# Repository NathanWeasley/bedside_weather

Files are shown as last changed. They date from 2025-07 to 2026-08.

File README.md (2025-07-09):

# Bedside Table Weather Station
An ESP8266/STM32G0-based LED matrix display designed to be a small-sized clock & weather station that can be placed on a bedside table.

## Why build this?
1. My wife has this habit that the first thing she does after wokeup is to fetch for her phone, ask siri about today's weather so she gets to know what to wear. A dedicated weather indicator makes this procedure simpler.
2. I just got a couple of this static monochrome 16x25 LED display module, with an STM32G070KBU6 that without its serial-wire debug interface disabled. The module is possibly scrapped from some electric bicycle since its default input voltage is up to 20V. Given reason 1, this module may just be the right component.
3. I just bought a Bambu Lab H2D, the performance and multifunctionality of this thing may just allow me to build a deligate enclosure for the weather station.

## Features (planned)
1. Weather + time acquisation from internet.
2. Vibration detect (slapping).
3. Brightness adaption.
4. Special effect pattern when not activated.

## First step: Reverse-Engineering the module
Since this is a pre-made module, first step is to reverse-engineer.

Objectives:
1. Finding power scheme - done
2. Finding MCU debug interface - done
3. Finding connections between MCU and LED drivers - done
4. Finding algorithms used to drive the LEDs - done

This is a static LED matrix - meaning in theory there is no need to do any form of scan, which then implies this module can reach ridiculously high refresh rates - 400 monochrome LEDs can be updated at 40kHz if a 16MHz shift clock is used.

The original firmware onboard automatically runs a test pattern of lighting all the LEDs at three different brightnesses. The algorithm used can be identified by probing the pins with an oscilloscope, and it turns out The original firmware does the grayscale control through brute-force Binary Code Modulation (BCM):

1. LAT signal is at 40kHz.
2. CLK signal is at 16MHz, and non-stopping.
3. DAT signal is at ~156Hz, all-low for full brightness. This is also the fps.
4. OE signal is always enabled.

Based on these observations, it's quite straight forward to calculate the update-per-frame as $40000 / 156 \approx 256$. This indicates the maximum grayscales this algorithm can reach is 8-bits. The only difference that in real BCM non-stopping update is not required, you do not need to update LEDs every tick, you only need to update 8 times at the correct timing.

This is actually more reasonable than original BCM because managing data transfer at the correct timing brings additional complexity to the system. Transferring same data many many times costs nothing but power consumption, which is of least concern in an LED-orinted product. And by the non-stoppping clock signal we can conclude the original firmware utilizes I2S+DMA (SPI+DMA will result in small delays between each transfer). DMA is set to circular mode.

The only issue with this design is its LAT output: Physically this signal comes from pin 16 of STM32G070KBU6, which is neither the NSS output of SPI, nor the WS output of I2S. Peripherals can be connected to this pin includes GPIO, Timers, USARTs and EVENTOUT. The possible scheme is to start a separate timer that is synchronized to the transfer and provide LAT signal through output compare.

## Second step: Replicate LED driver

Based on the hardware connections and the internal design, Since I'm unfamiliar with I2S I've decided to still go with SPI.

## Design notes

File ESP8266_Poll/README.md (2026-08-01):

# ESP8266 天气桥接器

本工程负责连接 Wi-Fi、通过 NTP 校时、获取心知天气的 3 天逐日预报，并通过 115200-8-N-1 串口向 STM32 发送二进制帧。逐小时预报代码仍然保留，但默认关闭。

## 配置与编译

1. 将 `secrets.example.h` 复制为 `secrets.h`，填写 Wi-Fi 和心知天气 API Key。`secrets.h` 已被 Git 忽略。
2. 在 `settings.h` 中设置地点、时区和刷新周期。默认地点为西安，时区为中国标准时间。
3. 使用 Arduino IDE 打开 `ESP8266_Poll.ino`，选择实际 ESP8266 板型后编译烧录。依赖 ESP8266 Arduino Core 和 ArduinoJson。

`settings.h` 中的 `ENABLE_HOURLY_FORECAST` 默认为 `0`，此时不会请求逐小时接口，也不会执行 08:00–18:00 天气变化提取。以后获得“24 小时逐小时天气预报”权限后可将其设为 `1`；逐小时接口只能返回当前时刻之后的数据，若设备在 08:00 以后才联网，天气响应的 `WEATHER_PARTIAL_DAY` 位会置 1。

## 串口协议

帧格式为：

`AA 55 | 地址(1) | 载荷长度小端(2) | 载荷(N) | 累加校验(1)`

校验值为地址、长度高字节、长度低字节以及全部载荷字节的 8 位累加和。所有多字节整数均按小端发送，所有载荷结构按 1 字节对齐。

MCU 请求载荷仅有一个字节：`1` 查询网络状态，`2` 查询时间，`3` 查询天气。响应地址如下：

| 地址 | 响应 | 载荷长度 |
| --- | --- | ---: |
| 10 | 网络状态 | 1 |
| 11 | 本地日期时间 | 9 |
| 12 | 天气汇总 | 81 |

天气汇总包含 3 天的最高/最低温、日间/夜间天气代码，以及当天 08:00–18:00 中“首个可用时点 + 天气代码变化时点”。结构的权威定义见 `protocol.hpp`；STM32 侧镜像定义位于 `App/v1/weather_protocol.h`。

## 运行策略

- 上电联网后立即拉取并主动发送一次天气与时间。
- 每次发送天气时，00:00（含）至 21:00（不含）把当天预报放入 `daily[0]`，21:00 起把次日预报放入 `daily[0]`；发出的 `daily_count` 为 1。
- 天气默认每 30 分钟刷新；失败后每 5 分钟重试，并在仍有旧数据时携带 `WEATHER_STALE` 标志返回缓存。
- 时间由 NTP 同步，每小时主动发送一次，也可由 MCU 随时查询。
- MCU 协议使用 `Serial`；可选调试日志使用 TX-only 的 `Serial1/GPIO2`，默认关闭，避免破坏二进制帧。

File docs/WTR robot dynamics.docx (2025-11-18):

Dynamics modelling of WTR robots

I Modelling the robot

For WTR robots, consider 3 connected links on the plane, with for following parameters:

| Link 1 | Link 2 | Link 3 | Link 4
Mass | m_1 | m_2 | m_3 | m_4
Length | L_1 =0 | L_2 | L_3 | L_4
Joint | d_1 | θ_2 | θ_3 | θ_4
Center of mass distance (w.r.t. head) | L_(c1) =0 | L_(c2) | L_(c3) | L_(c4)
Center of mass (w.r.t. head) | c_1 | c_2 | c_3 | c_4
Center of mass (w.r.t. world/base) | P_(c1) | P_(c2) | P_(c3) | P_(c4)
Inertia (w.r.t. CoM) | N/A | I_(zz2) | I_(zz3) | I_(zz4)

Green parameters are provided during design and considered as constants, blue parameters are derived parameters and are dependent of variables. Red parameters are the variables.
Associated frames and configuration are shown below:

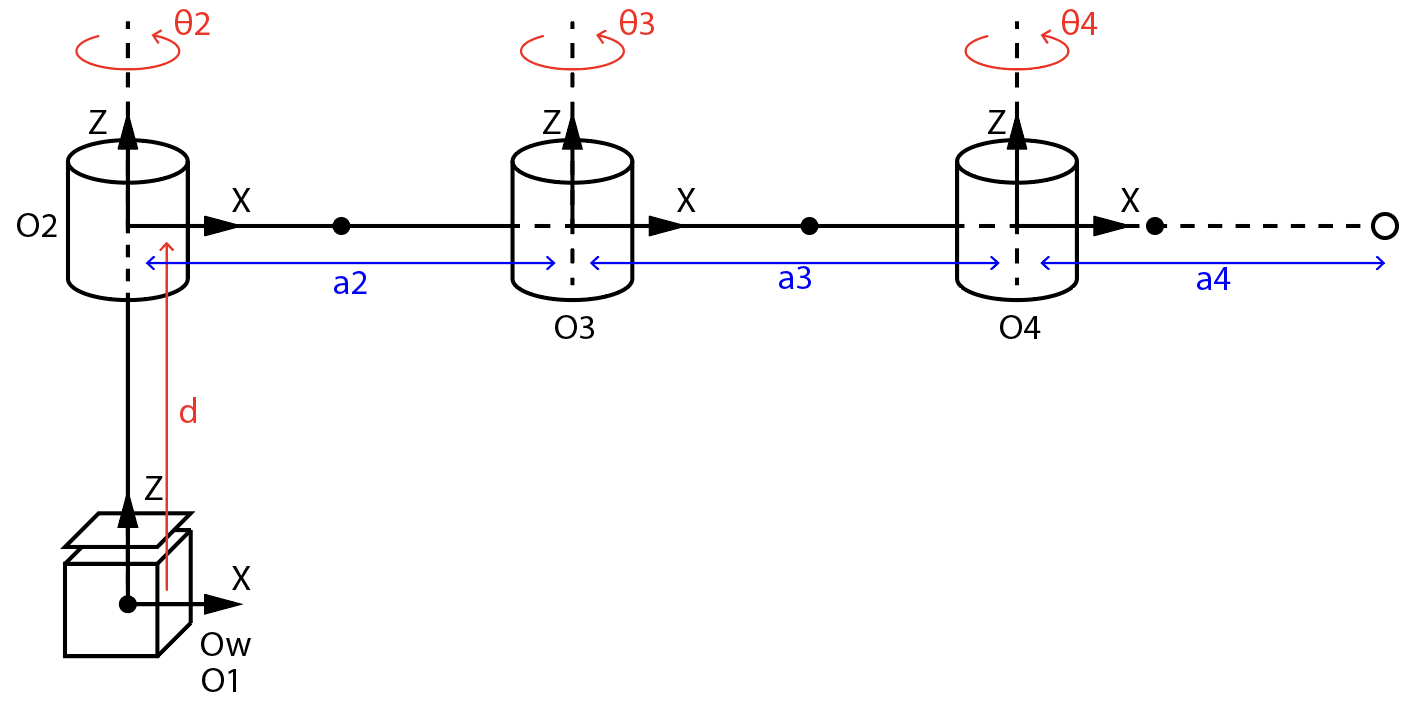
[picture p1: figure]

The corresponding modified DH parameters are:

i-th Joint | θ_i | a_(i-1) | d_i | α_(i-1) | Type
1 | 0 | 0 | q_1 =d_1 | 0 | Prismatic
2 | q_2 =θ_2 | L_1 | 0 | 0 | Revolute
3 | q_3 =θ_3 | L_2 | 0 | 0 | Revolute
4 | q_4 =θ_4 | L_3 | 0 | 0 | Revolute
5 | N/A | L_4 | N/A | 0 | N/A

II Deriving kinematic matrices

1. Using DH matrices

According to the modified DH convention, the transformation of a state in homogeneous coordinate is done by modelling the parameters θ,d,a,α sequentially:

T_i^(i-1) =Rot_X (α_(i-1) )Trans_X (a_(i-1) )Rot_Z (θ_i )Trans_Z (d_i ) =[cosθ_i , -sinθ_i , 0, a_(i-1) sinθ_i cosα_(i-1) , cosα_(i-1) cosθ_i , -sinα_(i-1) , -sinα_(i-1) d_i sinθ_i sinα_(i-1) , sinα_(i-1) cosθ_i , cosα_(i-1) , cosα_(i-1) d_i 0, 0, 0, 1]

Note the 0-th DH parameter is considered to be zero.

Since for WTR/SCARA-type robots, we always have α_i =0 , T_i^(i-1) can be simplified:

T_i^(i-1) =[cosθ_i , -sinθ_i , 0, a_(i-1) sinθ_i , cosθ_i , 0, 00, 0, 1, d_i 0, 0, 0, 1]

For all 4 joints, we have the total transformation matrix:

T_4^0 =T_1^0 T_2^1 T_3^2 T_4^3

Or generally for the i-th link, the transformation matrix can be defined as:

T_i^0 =∏_(j=1)^i T_j^(j-1)

And for mass center c_i defined in the local frame of each link, they can be transformed into world frame:

c_i^0 =T_i^0 c_i =P_(ci)

Deriving the mass center of each link is crucial for constructing the Lagrangian – we need the kinetic energy and potential energy for each link, which are usually defined around the link’s mass center.

2. Using direct geometrical calculation

Another way of deriving the mass center location is through the geometry of the robot, which involves no transformation matrices. This method can be intuitive for robots with only a few joints.

First, we derive position of the end point of each link:

p_0 =(0, 0,0)^T p_1 =p_0 +(0,0,d_1 )^T =(0,0,d_1 )^T p_2 =p_1 +(L_2 cosθ_2 ,L_2 sinθ_2 ,0)^T =(L_2 cosθ_2 ,L_2 sinθ_2 ,d_1 )^T p_3 =p_2 +(L_3 cos(θ_2 +θ_3 ),L_3 sin(θ_2 +θ_3 ),0)^T =(L_2 cosθ_2 +L_3 cos(θ_2 +θ_3 ),L_2 sinθ_2 +L_3 sin(θ_2 +θ_3 ),d_1 )^T p_4 =p_3 +(L_4 cos(θ_2 +θ_3 +θ_4 ),L_4 sin(θ_2 +θ_3 +θ_4 ),0)^T =(, L_2 cosθ_2 +L_3 cos(θ_2 +θ_3 )+L_4 cos(θ_2 +θ_3 +θ_4 ), L_2 sinθ_2 +L_3 sin(θ_2 +θ_3 )+L_4 sin(θ_2 +θ_3 +θ_4 ), d_1 )

We can derive the center of mass w.r.t. the rotation axis (origin) of each link.

c_1 =(0,0,d_1 )^T c_2 =(L_(c2) cosθ_2 ,L_(c2) sinθ_2 ,0)^T c_3 =(L_(c3) cos(θ_2 +θ_3 ),L_(c3) sin(θ_2 +θ_3 ),0)^T c_4 =(L_(c4) cos(θ_2 +θ_3 +θ_4 ), L_(c4) sin(θ_2 +θ_3 +θ_4 ),0)^T

Combined we have the position of each mass center in the world frame:

P_(c1) =c_1 +p_0 =(0,0,d_1 )^T P_(c2) =c_2 +p_1 =(L_(c2) cosθ_2 ,L_(c2) sinθ_2 ,d_1 )^T P_(c3) =c_3 +p_2 =(L_(c3) cos(θ_2 +θ_3 )+L_2 cosθ_2 ,L_(c3) sin(θ_2 +θ_3 )+L_2 sinθ_2 ,d_1 )^T P_(c4) =c_4 +p_3 =(, L_(c4) cos(θ_2 +θ_3 +θ_4 )+L_2 cosθ_2 +L_3 cos(θ_2 +θ_3 ), L_(c4) sin(θ_2 +θ_3 +θ_4 )+L_2 sinθ_2 +L_3 sin(θ_2 +θ_3 ), d_1 )

With the help of the CAS system in MATLAB we can verify the two methods yield the same result.

III Forming the Lagrangian

The Lagrangian is defined by L=K-U , in which K is the total kinetic energy of the system and U is the total potential energy of the system. Physically the above energies can be defined using the object’s mass center:

K_i =1/2m_i v_(ci)^T v_(ci) +1/2ω_i^T I_i ω_i

For WTR/SCARA-type robots, all joints rotate around their Z axis, therefore the second term can be simplified to only involving the joint velocity and the inertia around the Z axis at the mass center:

K_i =1/2m_i v_(ci)^T v_(ci) +1/2I_(zzi) θ_i^2

1. Kinetic energy using joint velocity

Since in the end we want the relationship between joint torque and joint position, velocity, acceleration, etc., it’s better to formulate kinetic energy in terms of the joint variables q, q,q . This can be done by taking the derivative of mass centers w.r.t. joint variables, more specifically, joint velocities:

K_i =1/2q^T D_i (q)q D_i =(∂P_(ci))/(∂q)

D_i (q) is called the inertia matrix of this link. The total kinetic energy K is formed by summing individual kinetic energy of each link:

K=∑_(i=1)^n K_i =1/2q^T M(q)q

M(q) is called the mass matrix of the robot. As later we’ll see, this is one of the terms we want for calculating the inverse dynamics.

Deriving the mass matrix by taking derivatives can be a mess if you do it by hand. Instead, it can be done by utilizing link Jacobian:

J_i =[J_(vi)^T , J_(ωi)^T ]^T

The link Jacobian transforms the joint velocity to velocity of the link’s mass center in world frame.

Link Jacobian can be derived as:

J_i =[r_(vi_1) , r_(vi_2) , ⋯, r_(vi_n) r_(ωi_1) , r_(ωi_2) , ⋯, r_(ωi_n) ]_(6×n)

For revolute joints:

r_(vi_j) ={, z_j ×(P_(ci) -p_j ), j≤i, 0, j>i r_(ωi_j) ={, z_j , j≤i, 0, j>i

For prismatic joints:

r_(vi_j) ={, z_j , j≤i, 0, j>i r_(ωi_j) =0

z_j is the representation of Z axis of the j-th link in world frame, it’s also the third column of the rotation matrix part in the total homogeneous matrix up till this link: p_j represents the origin of the j-th link, it’s also the translational part of the total homogeneous matrix up till this link.

T_j^0 =[R_j^0 , p_j 0, 1]=[[x_j , y_j , z_j ], p_j 0, 1]

In total the link Jacobian provides the overall contribution of each joint to the i-th mass center in world frame. Utilizing the link Jacobian, link velocity and angular velocity is just:

v_(ci) =J_(vi) q ω_i =J_(ωi) q

In order to calculate energy, we need the inertia of each link to be represented in the world frame. This can be done by utilizing the rotation part of the total homogeneous matrix up till this link:

I_i^0 =R_i^0 I_i R_i^0 ^T

Finally, we can rewrite the kinetic energy in these terms:

K_i =1/2m_i (J_(vi) q)^T (J_(vi) q)+1/2(J_(ωi) q)^T I_i^0 (J_(ωi) q) =1/2q^T m_i J_(vi)^T J_(vi) q+1/2q^T J_(ωi)^T I_i^0 J_(ω_i) q =1/2q^T D_i (q)q

Among which:

D_i (q)=m_i J_(vi)^T J_(vi) +J_(ωi)^T I_i^0 J_(ω_i)

And adding the above kinetic energy for all links we have the explicit form of total kinetic energy, also the mass matrix.

For the potential energy, it’s only related to gravity (no springs are involved):

U_i =[0, 0, 1]m_i gp_i

2. Kinetic energy using Cartesian velocity

If you already derived the mass center location in analytical form, then the most intuitive way is to get velocity simply by taking its derivative w.r.t. time.

For later simplicity we calculate local direction of each link in world frame:

r_1 =(, 0, 0, 1) r_2 =(, -sinθ_2 , cosθ_2 , 0) r_3 =（, -sin（θ_2 +θ_3 ）, cos（θ_2 +θ_3 ）, 0） r_4 =(, -sin(θ̇_2 +θ_3 +θ_4 ), cos(θ̇_2 +θ_3 +θ_4 ), 0)

Mass center velocity can be seen as a combination of the above directions:

v_(c1) =d_1 r_1 v_(c2) =L_(c2) θ_2 r_2 +d_1 r_1 v_(c3) =L_(c3) (θ_2 +θ_3 )r_3 +L_2 θ_2 r_2 +d_1 r_1 v_(c4) =L_(c4) (θ_2 +θ_3 +θ_4 )r_4 +L_3 (θ_2 +θ_3 )r_3 +L_2 θ_2 r_2 +d_1 r_1

We then derive kinetic and potential energy for each link.

Kinetic energy (described per link as the combination of rotational and translational movement):

K_1 =1/2m_1 v_(c1)^2 K_2 =1/2I_(zz2) θ_2^2 +1/2m_2 v_(c2)^2 K_3 =1/2I_(zz3) (θ_2 +θ_3 )^2 +1/2m_3 v_(c3)^2 K_4 =1/2I_(zz4) (θ_2 +θ_3 +θ_4 )^2 +1/2m_4 v_(c4)^2

Potential energy:

U_1 =m_1 gd_1 U_2 =m_2 gd_1 U_3 =m_3 gd_1 U_4 =m_4 gd_1

IV Solving the Euler-Lagrange equation

Given Lagrangian L , we have total generalized (non-conservative) force defined by the Euler-Lagrange equation:

d/(dt)((∂L)/(∂q))-(∂L)/(∂q)=F

Inverse dynamics involves solving this equation for F .

Since L is a function of q, q only, (∂L)/(∂q) is also a function of q, q only. This means the time derivative term can be expanded using chain rule:

d/(dt)((∂L)/(∂q))=(∂^2 L)/(∂q∂q)q+(∂^2 L)/(∂q^2)q

Which yields:

F=(∂^2 L)/(∂q∂q)q+(∂^2 L)/(∂q^2)q-(∂L)/(∂q)

Since we have the Lagrangian in analytical form, we can calculate each of the derivatives effectively and accurately using the technique of reverse mode automatic differentiation.

Actually, the Hessian of Lagrangian w.r.t. general velocity q is equivalent to the mass matrix M(q) , and one can directly notice that the above equation is the exact motion equation:

F=M(q)q+C(q,q)q+g(q)

Where:

M(q)=(∂^2 L)/(∂q^2) C(q,q)=(∂^2 L)/(∂q∂q) g(q)=-(∂L)/(∂q)

Note that in this direct method, the Coriolis and centrifugal matrix C(q,q) and gravity term g(q) is not unique, and it can be different from the same equation derived from other methods.

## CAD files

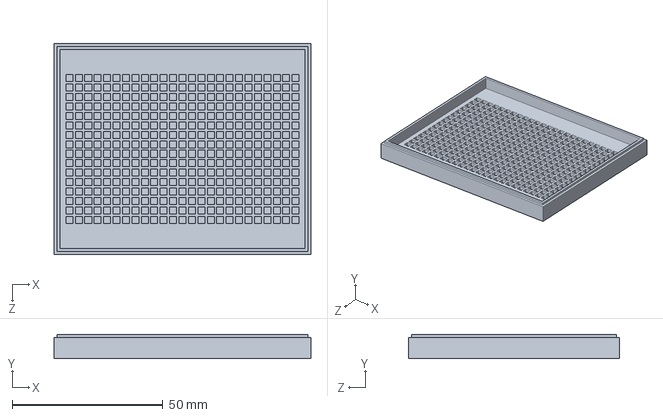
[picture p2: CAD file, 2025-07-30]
enclosure/front.SLDPRT
85.2 x 8.00 x 70.0 mm

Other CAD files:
enclosure/front_nopiller.STL
enclosure/front.STL

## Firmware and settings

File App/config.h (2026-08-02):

#pragma once

#include <stdint.h>

#ifdef __cplusplus
extern "C"
{
#endif

#define LED_HEIGHT              (16)
#define LED_WIDTH               (25)
#define LED_COLOR_DEPTH         (8)

#define LED_CNT                 (LED_HEIGHT * LED_WIDTH)
#define LED_BUFFER_SIZE         (LED_CNT/8 + ((LED_CNT%8) == 0 ? 0 : 1))
#define LED_GRAYSCALE           (1 << LED_COLOR_DEPTH)

#define DEFAULT_RX_BUFFER_SIZE  (512)
#define DEFAULT_TX_BUFFER_SIZE  (64)
#define UART_BUFFER_SIZE        (1024)

#define GFX_VPAINT_MAX_WIDTH    (500)
#define GFX_VPAINT_MAX_HEIGHT   (32)

#define TASK_MAX_TASKS          (16)
#define TASK_SCHEDULE_PERIOD_US (10000)     // 10 ms -> 100 Hz

#ifdef __cplusplus
}
#endif

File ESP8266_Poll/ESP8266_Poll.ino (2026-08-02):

#include <Arduino.h>
#include <ArduinoJson.h>
#include <ESP8266HTTPClient.h>
#include <ESP8266WiFi.h>
#include <ESP8266WiFiMulti.h>
#include <WiFiClientSecureBearSSL.h>

#include <cmath>
#include <cstdlib>
#include <ctime>

#include "protocol.hpp"
#include "secrets.h"
#include "settings.h"

using namespace bedside;

#if ENABLE_DEBUG_LOG
#define DEBUG_BEGIN(baud) Serial1.begin(baud)
#define DEBUG_PRINT(...) Serial1.print(__VA_ARGS__)
#define DEBUG_PRINTLN(...) Serial1.println(__VA_ARGS__)
#define DEBUG_PRINTF(...) Serial1.printf(__VA_ARGS__)
#else
#define DEBUG_BEGIN(baud) ((void)(baud))
#define DEBUG_PRINT(...) ((void)0)
#define DEBUG_PRINTLN(...) ((void)0)
#define DEBUG_PRINTF(...) ((void)0)
#endif

namespace
{

enum class FetchResult : uint8_t
{
    OK = 0,
    NETWORK_ERROR,
    HTTP_ERROR,
    JSON_ERROR,
};

const char* fetchResultName(FetchResult result)
{
    switch (result)
    {
    case FetchResult::OK:
        return "OK";
    case FetchResult::NETWORK_ERROR:
        return "NETWORK_ERROR";
    case FetchResult::HTTP_ERROR:
        return "HTTP_ERROR";
    case FetchResult::JSON_ERROR:
        return "JSON_ERROR";
    default:
        return "UNKNOWN";
    }
}

const char* wifiStatusName(int status)
{
    switch (status)
    {
    case WL_IDLE_STATUS:
        return "IDLE";
    case WL_NO_SSID_AVAIL:
        return "NO_SSID";
    case WL_SCAN_COMPLETED:
        return "SCAN_COMPLETED";
    case WL_CONNECTED:
        return "CONNECTED";
    case WL_CONNECT_FAILED:
        return "CONNECT_FAILED";
    case WL_CONNECTION_LOST:
        return "CONNECTION_LOST";
    case WL_DISCONNECTED:
        return "DISCONNECTED";
    default:
        return "UNKNOWN";
    }
}

String redactApiKey(const String& url)
{
    String safeUrl = url;
    const int keyStart = safeUrl.indexOf(F("key="));
    if (keyStart < 0)
    {
        return safeUrl;
    }

    const int valueStart = keyStart + 4;
    int valueEnd = safeUrl.indexOf('&', valueStart);
    if (valueEnd < 0)
    {
        valueEnd = safeUrl.length();
    }
    String redacted = safeUrl.substring(0, valueStart);
    redacted += F("<redacted>");
    redacted += safeUrl.substring(valueEnd);
    return redacted;
}

bool timeReached(uint32_t now, uint32_t deadline)
{
    return static_cast<int32_t>(now - deadline) >= 0;
}

bool parseIsoDateTime(const char* value, uint16_t& year, uint8_t& month, uint8_t& day, uint8_t& hour)
{
    if (value == nullptr || strlen(value) < 13 || value[4] != '-' || value[7] != '-' || value[10] != 'T')
    {
        return false;
    }

    year = static_cast<uint16_t>(atoi(value));
    month = static_cast<uint8_t>(atoi(value + 5));
    day = static_cast<uint8_t>(atoi(value + 8));
    hour = static_cast<uint8_t>(atoi(value + 11));
    return year >= 2000 && month >= 1 && month <= 12 && day >= 1 && day <= 31 && hour <= 23;
}

bool parseIsoDate(const char* value, uint16_t& year, uint8_t& month, uint8_t& day)
{
    uint8_t ignoredHour = 0;
    if (value == nullptr || strlen(value) < 10)
    {
        return false;
    }

    char dateTime[14] = {0};
    memcpy(dateTime, value, 10);
    memcpy(dateTime + 10, "T00", 3);
    return parseIsoDateTime(dateTime, year, month, day, ignoredHour);
}

WeatherType parseWeatherCode(JsonVariantConst value)
{
    if (value.isNull())
    {
        return WeatherType::UNKNOWN;
    }

    const int code = value.as<int>();
    if (code >= static_cast<int>(WeatherType::DAY_SUNNY) && code <= static_cast<int>(WeatherType::HOT))
    {
        return static_cast<WeatherType>(code);
    }
    return WeatherType::UNKNOWN;
}

int16_t parseTemperatureX10(JsonVariantConst value)
{
    long result = lroundf(value.as<float>() * 10.0F);
    if (result < INT16_MIN)
    {
        result = INT16_MIN;
    }
    else if (result > INT16_MAX)
    {
        result = INT16_MAX;
    }
    return static_cast<int16_t>(result);
}

void applyFetchError(uint8_t& status, FetchResult result)
{
    switch (result)
    {
    case FetchResult::NETWORK_ERROR:
        status |= WEATHER_NETWORK_ERROR;
        break;
    case FetchResult::HTTP_ERROR:
        status |= WEATHER_HTTP_ERROR;
        break;
    case FetchResult::JSON_ERROR:
        status |= WEATHER_JSON_ERROR;
        break;
    default:
        break;
    }
}

} // namespace

class WeatherBridge
{
    enum class ReadState : uint8_t
    {
        HEADER_AA = 0,
        HEADER_55,
        ADDRESS,
        LENGTH_LOW,
        LENGTH_HIGH,
        DATA,
    };

    ESP8266WiFiMulti _wifi;
    v1::Packet _rxPacket;
    v1::Packet _txPacket;
    WeatherResponse _weather{};
    ReadState _readState = ReadState::HEADER_AA;
    uint8_t* _nextRxByte = nullptr;
    uint16_t _rxBytesLeft = 0;
    uint32_t _nextWifiPoll = 0;
    uint32_t _nextWeatherRefresh = 0;
    uint32_t _nextDateTimePush = 0;
    bool _ntpStarted = false;
    bool _weatherRefreshPending = true;
    bool _lastFetchFailed = false;
    bool _wasConnected = false;
    bool _clockStatusLogged = false;
    int _lastWifiStatus = -1;

public:
    void begin()
    {
        Serial.begin(115200);
        DEBUG_BEGIN(115200);

        resetPacketReader();
        WiFi.persistent(false);
        WiFi.mode(WIFI_STA);
        WiFi.setAutoReconnect(true);
        _wifi.addAP(WIFI_SSID, WIFI_PASSWORD);

        // 用 UTC 同步系统时钟，再由 TZ 规则转换为本地时间。
        setenv("TZ", DEVICE_TIMEZONE, 1);
        tzset();
        DEBUG_PRINTLN(F("[BOOT] ESP8266 weather bridge started"));
        DEBUG_PRINTF("[BOOT] target_ssid=%s, weather_location=%s, debug_uart=Serial1/GPIO2\n",
                     WIFI_SSID, WEATHER_LOCATION);
        logWifiStatus(WiFi.status());
    }

    void tick()
    {
        processSerial();

        const uint32_t now = millis();
        if (timeReached(now, _nextWifiPoll))
        {
            _wifi.run();
            _nextWifiPoll = now + WIFI_POLL_INTERVAL_MS;

            const int wifiStatus = WiFi.status();
            if (wifiStatus != _lastWifiStatus)
            {
                logWifiStatus(wifiStatus);
            }
        }

        const bool connected = WiFi.status() == WL_CONNECTED;
        if (connected && !_wasConnected)
        {
            // 每次重新联网都立即刷新，避免继续展示断网前的缓存。
            _weatherRefreshPending = true;
        }
        _wasConnected = connected;

        if (connected)
        {
            if (!_ntpStarted)
            {
                DEBUG_PRINTF("[NTP] starting synchronization, timezone=%s\n", DEVICE_TIMEZONE);
                // 使用 POSIX 时区重载；数值型 configTime(0, 0, ...) 会把本地时区重置为 GMT。
                configTime(DEVICE_TIMEZONE, "ntp.aliyun.com", "ntp1.aliyun.com", "pool.ntp.org");
                _ntpStarted = true;
            }

            if (isClockValid() && !_clockStatusLogged)
            {
                logCurrentTime();
                _clockStatusLogged = true;
            }

            if (_weatherRefreshPending || timeReached(now, _nextWeatherRefresh))
            {
                const bool complete = refreshWeather();
                _weatherRefreshPending = false;
                _nextWeatherRefresh = now + (complete ? WEATHER_REFRESH_INTERVAL_MS : WEATHER_RETRY_INTERVAL_MS);
                sendWeather();
            }

            if (isClockValid() && timeReached(now, _nextDateTimePush))
            {
                sendDateTime();
                _nextDateTimePush = now + DATETIME_PUSH_INTERVAL_MS;
            }
        }

        yield();
    }

private:
    String makeWeatherUrl(const __FlashStringHelper* resource, const __FlashStringHelper* suffix) const
    {
        String url;
        url.reserve(192);
        url += F("https://api.seniverse.com/v3/weather/");
        url += resource;
        url += F(".json?key=");
        url += SENIVERSE_API_KEY;
        url += F("&location=");
        url += WEATHER_LOCATION;
        url += F("&language=");
        url += WEATHER_LANGUAGE;
        url += F("&unit=");
        url += WEATHER_UNIT;
        url += suffix;
        return url;
    }

    FetchResult httpGet(const String& url, String& payload)
    {
        if (WiFi.status() != WL_CONNECTED)
        {
            DEBUG_PRINTF("[HTTP] skipped: WiFi status=%s(%d)\n",
                         wifiStatusName(WiFi.status()), static_cast<int>(WiFi.status()));
            return FetchResult::NETWORK_ERROR;
        }

        const String safeUrl = redactApiKey(url);
        DEBUG_PRINTF("[HTTP] GET %s\n", safeUrl.c_str());
        const uint32_t startedAt = millis();

        BearSSL::WiFiClientSecure client;
        // ESP8266 未内置稳定的 CA 存储；HTTPS 仍可避免 API key 明文传输。
        // 如产品化部署，应改为 setTrustAnchors() 并随证书更新固件。
        client.setInsecure();

        HTTPClient http;
        http.setTimeout(HTTP_TIMEOUT_MS);
        if (!http.begin(client, url))
        {
            DEBUG_PRINTF("[HTTP] begin failed after %lu ms\n",
                         static_cast<unsigned long>(millis() - startedAt));
            return FetchResult::HTTP_ERROR;
        }

        const int code = http.GET();
        if (code > 0)
        {
            payload = http.getString();
        }
        const uint32_t elapsed = millis() - startedAt;
        DEBUG_PRINTF("[HTTP] response: code=%d, elapsed=%lu ms, bytes=%u\n",
                     code, static_cast<unsigned long>(elapsed), static_cast<unsigned>(payload.length()));

        if (code != HTTP_CODE_OK)
        {
            if (code < 0)
            {
                DEBUG_PRINTF("[HTTP] transport error: %s\n", http.errorToString(code).c_str());
            }
            else if (payload.length() > 0)
            {
                // 403 等业务错误的正文通常包含心知天气错误码，限制长度避免刷屏。
                constexpr unsigned int MAX_ERROR_BODY_LOG = 512;
                if (payload.length() > MAX_ERROR_BODY_LOG)
                {
                    payload.remove(MAX_ERROR_BODY_LOG);
                    payload += F("...<truncated>");
                }
                DEBUG_PRINTF("[HTTP] error body: %s\n", payload.c_str());
            }
            http.end();
            return code < 0 ? FetchResult::NETWORK_ERROR : FetchResult::HTTP_ERROR;
        }

        http.end();
        return payload.length() > 0 ? FetchResult::OK : FetchResult::HTTP_ERROR;
    }

    FetchResult fetchDaily(WeatherResponse& output)
    {
        String payload;
        FetchResult result = httpGet(makeWeatherUrl(F("daily"), F("&start=0&days=3")), payload);
        if (result != FetchResult::OK)
        {
            return result;
        }

#if ARDUINOJSON_VERSION_MAJOR >= 7
        JsonDocument document;
#else
        DynamicJsonDocument document(6144);
#endif
        const DeserializationError error = deserializeJson(document, payload);
        if (error)
        {
            DEBUG_PRINTF("Daily JSON error: %s\n", error.c_str());
            return FetchResult::JSON_ERROR;
        }

        JsonArrayConst daily = document["results"][0]["daily"].as<JsonArrayConst>();
        if (daily.isNull())
        {
            return FetchResult::JSON_ERROR;
        }

        output.daily_count = 0;
        for (JsonObjectConst item : daily)
        {
            if (output.daily_count >= DAILY_FORECAST_COUNT)
            {
                break;
            }

            DailyForecast& day = output.daily[output.daily_count];
            if (!parseIsoDate(item["date"].as<const char*>(), day.year, day.month, day.day) ||
                item["high"].isNull() || item["low"].isNull())
            {
                continue;
            }

            day.temp_max_x10 = parseTemperatureX10(item["high"]);
            day.temp_min_x10 = parseTemperatureX10(item["low"]);
            day.weather_day = parseWeatherCode(item["code_day"]);
            day.weather_night = parseWeatherCode(item["code_night"]);
            ++output.daily_count;
        }

        if (output.daily_count == 0)
        {
            return FetchResult::JSON_ERROR;
        }
        output.status |= WEATHER_DAILY_VALID;
        DEBUG_PRINTF("[WEATHER] daily parsed: days=%u\n", output.daily_count);
        for (uint8_t i = 0; i < output.daily_count; ++i)
        {
            const DailyForecast& day = output.daily[i];
            DEBUG_PRINTF("[WEATHER] daily[%u]: %04u-%02u-%02u, high=%s%d.%dC, low=%s%d.%dC, day=%u, night=%u\n",
                         i, day.year, day.month, day.day,
                         day.temp_max_x10 < 0 ? "-" : "", abs(day.temp_max_x10) / 10, abs(day.temp_max_x10) % 10,
                         day.temp_min_x10 < 0 ? "-" : "", abs(day.temp_min_x10) / 10, abs(day.temp_min_x10) % 10,
                         static_cast<unsigned>(day.weather_day), static_cast<unsigned>(day.weather_night));
        }
        return FetchResult::OK;
    }

#if ENABLE_HOURLY_FORECAST
    FetchResult fetchHourly(WeatherResponse& output)
    {
        String payload;
        FetchResult result = httpGet(makeWeatherUrl(F("hourly"), F("&start=0&hours=24")), payload);
        if (result != FetchResult::OK)
        {
            return result;
        }

#if ARDUINOJSON_VERSION_MAJOR >= 7
        JsonDocument document;
#else
        DynamicJsonDocument document(12288);
#endif
        const DeserializationError error = deserializeJson(document, payload);
        if (error)
        {
            DEBUG_PRINTF("Hourly JSON error: %s\n", error.c_str());
            return FetchResult::JSON_ERROR;
        }

        JsonArrayConst hourly = document["results"][0]["hourly"].as<JsonArrayConst>();
        if (hourly.isNull())
        {
            return FetchResult::JSON_ERROR;
        }

        uint16_t targetYear = 0;
        uint8_t targetMonth = 0;
        uint8_t targetDay = 0;
        if (output.daily_count > 0)
        {
            targetYear = output.daily[0].year;
            targetMonth = output.daily[0].month;
            targetDay = output.daily[0].day;
        }
        else if (!getLocalDate(targetYear, targetMonth, targetDay))
        {
            const char* firstTime = hourly[0]["time"] | "";
            uint8_t ignoredHour = 0;
            if (!parseIsoDateTime(firstTime, targetYear, targetMonth, targetDay, ignoredHour))
            {
                return FetchResult::JSON_ERROR;
            }
        }

        output.change_count = 0;
        bool foundWindowData = false;
        uint8_t firstHour = 0xFF;
        uint8_t lastHour = 0;
        WeatherType previousWeather = WeatherType::UNKNOWN;

        for (JsonObjectConst item : hourly)
        {
            uint16_t year = 0;
            uint8_t month = 0;
            uint8_t day = 0;
            uint8_t hour = 0;
            if (!parseIsoDateTime(item["time"].as<const char*>(), year, month, day, hour) ||
                year != targetYear || month != targetMonth || day != targetDay || hour < 8 || hour > 18)
            {
                continue;
            }

            const WeatherType weather = parseWeatherCode(item["code"]);
            if (!foundWindowData)
            {
                firstHour = hour;
            }
            foundWindowData = true;
            lastHour = hour;

            // 只记录首个时点和天气现象发生变化的时点，避免传输重复数据。
            if (output.change_count == 0 || weather != previousWeather)
            {
                if (output.change_count < HOURLY_CHANGE_COUNT)
                {
                    HourlyWeatherChange& change = output.changes[output.change_count++];
                    change.hour = hour;
                    change.temperature_x10 = parseTemperatureX10(item["temperature"]);
                    change.weather = weather;
                }
            }
            previousWeather = weather;
        }

        output.status |= WEATHER_HOURLY_VALID;
        if (!foundWindowData || firstHour > 8 || lastHour < 18)
        {
            // 逐小时接口仅返回“当前起未来 24 小时”，午后启动时当天早间数据天然不完整。
            output.status |= WEATHER_PARTIAL_DAY;
        }
        DEBUG_PRINTF("[WEATHER] hourly parsed: changes=%u, first_hour=%d, last_hour=%d, partial=%s\n",
                     output.change_count,
                     foundWindowData ? static_cast<int>(firstHour) : -1,
                     foundWindowData ? static_cast<int>(lastHour) : -1,
                     (output.status & WEATHER_PARTIAL_DAY) != 0 ? "yes" : "no");
        for (uint8_t i = 0; i < output.change_count; ++i)
        {
            const HourlyWeatherChange& change = output.changes[i];
            DEBUG_PRINTF("[WEATHER] change[%u]: hour=%02u, temp=%s%d.%dC, weather=%u\n",
                         i, change.hour,
                         change.temperature_x10 < 0 ? "-" : "",
                         abs(change.temperature_x10) / 10, abs(change.temperature_x10) % 10,
                         static_cast<unsigned>(change.weather));
        }
        return FetchResult::OK;
    }
#endif

    bool refreshWeather()
    {
        WeatherResponse fresh{};
        const FetchResult dailyResult = fetchDaily(fresh);

#if ENABLE_HOURLY_FORECAST
        // 心知天气的基础访问频率可能只有 1 次/秒，两类接口之间主动留出间隔。
        delay(API_MIN_REQUEST_INTERVAL_MS);
        const FetchResult hourlyResult = fetchHourly(fresh);
#else
        DEBUG_PRINTLN(F("[WEATHER] hourly forecast disabled by configuration"));
#endif

        if (dailyResult != FetchResult::OK && (_weather.status & WEATHER_DAILY_VALID) != 0)
        {
            fresh.daily_count = _weather.daily_count;
            memcpy(fresh.daily, _weather.daily, sizeof(fresh.daily));
            fresh.status |= WEATHER_DAILY_VALID | WEATHER_STALE;
        }

#if ENABLE_HOURLY_FORECAST
        if (hourlyResult != FetchResult::OK && (_weather.status & WEATHER_HOURLY_VALID) != 0)
        {
            fresh.change_count = _weather.change_count;
            memcpy(fresh.changes, _weather.changes, sizeof(fresh.changes));
            fresh.status |= WEATHER_HOURLY_VALID | WEATHER_STALE;
            fresh.status |= _weather.status & WEATHER_PARTIAL_DAY;
        }
#endif

        applyFetchError(fresh.status, dailyResult);
#if ENABLE_HOURLY_FORECAST
        applyFetchError(fresh.status, hourlyResult);
#endif
        fresh.updated_at = isClockValid() ? static_cast<uint32_t>(time(nullptr)) : 0;
        _weather = fresh;
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
void loop()
{
    weatherBridge.tick();
}

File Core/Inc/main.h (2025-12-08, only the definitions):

#define OE_Pin LL_GPIO_PIN_7
#define OE_GPIO_Port GPIOA
#define LAT_Pin LL_GPIO_PIN_1
#define LAT_GPIO_Port GPIOB
#define OE_H    (OE_GPIO_Port->BSRR=OE_Pin)
#define OE_L    (OE_GPIO_Port->BRR=OE_Pin)
#define LAT_H    (LAT_GPIO_Port->BSRR=LAT_Pin)
#define LAT_L    (LAT_GPIO_Port->BRR=LAT_Pin)
#define CLK_H    (CLK_GPIO_Port->BSRR=CLK_Pin)
#define CLK_L    (CLK_GPIO_Port->BRR=CLK_Pin)
#define DAT_H    (DAT_GPIO_Port->BSRR=DAT_Pin)
#define DAT_L    (DAT_GPIO_Port->BRR=DAT_Pin)

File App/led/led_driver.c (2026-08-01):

#include "led/led_driver.h"
#include "main.h"
#include <string.h>

static led_breakdown_t  g_led_breakdown;

#define LED_BCM_TIME_UNIT_US       (25U)
#define LED_DMA_RETRY_TIME_US      (25U)

#if LED_COLOR_DEPTH != 8
#error "当前BCM权重表仅支持8位灰度"
#endif

static const uint16_t g_weight_table[LED_COLOR_DEPTH] =
{
    128U, 64U, 32U, 16U, 8U, 4U, 2U, 1U
};

static uint8_t          g_pending_bit;
static uint8_t          g_display_started;
static volatile uint32_t g_refresh_error_count;

static const uint8_t    g_img2buf_idx[LED_CNT] =
{
    0,  2,  2,  2,  2,  4,  4,  4,  4,  6,  6,  6,  6,  8,  8,  8,  8, 10, 10, 10, 10, 12, 12, 12, 12,
    0,  2,  2,  2,  2,  4,  4,  4,  4,  6,  6,  6,  6,  8,  8,  8,  8, 10, 10, 10, 10, 12, 12, 12, 12,
    0,  3,  3,  3,  3,  5,  5,  5,  5,  7,  7,  7,  7,  9,  9,  9,  9, 11, 11, 11, 11, 13, 13, 13, 13,
    0,  3,  3,  3,  3,  5,  5,  5,  5,  7,  7,  7,  7,  9,  9,  9,  9, 11, 11, 11, 11, 13, 13, 13, 13,
    0, 14, 14, 14, 14, 16, 16, 16, 16, 18, 18, 18, 18, 20, 20, 20, 20, 22, 22, 22, 22, 24, 24, 24, 24,
    0, 14, 14, 14, 14, 16, 16, 16, 16, 18, 18, 18, 18, 20, 20, 20, 20, 22, 22, 22, 22, 24, 24, 24, 24,
    0, 15, 15, 15, 15, 17, 17, 17, 17, 19, 19, 19, 19, 21, 21, 21, 21, 23, 23, 23, 23, 25, 25, 25, 25,
    0, 15, 15, 15, 15, 17, 17, 17, 17, 19, 19, 19, 19, 21, 21, 21, 21, 23, 23, 23, 23, 25, 25, 25, 25,
    1, 26, 26, 26, 26, 28, 28, 28, 28, 30, 30, 30, 30, 32, 32, 32, 32, 34, 34, 34, 34, 36, 36, 36, 36,
    1, 26, 26, 26, 26, 28, 28, 28, 28, 30, 30, 30, 30, 32, 32, 32, 32, 34, 34, 34, 34, 36, 36, 36, 36,
    1, 27, 27, 27, 27, 29, 29, 29, 29, 31, 31, 31, 31, 33, 33, 33, 33, 35, 35, 35, 35, 37, 37, 37, 37,
    1, 27, 27, 27, 27, 29, 29, 29, 29, 31, 31, 31, 31, 33, 33, 33, 33, 35, 35, 35, 35, 37, 37, 37, 37,
    1, 38, 38, 38, 38, 40, 40, 40, 40, 42, 42, 42, 42, 44, 44, 44, 44, 46, 46, 46, 46, 48, 48, 48, 48,
    1, 38, 38, 38, 38, 40, 40, 40, 40, 42, 42, 42, 42, 44, 44, 44, 44, 46, 46, 46, 46, 48, 48, 48, 48,
    1, 39, 39, 39, 39, 41, 41, 41, 41, 43, 43, 43, 43, 45, 45, 45, 45, 47, 47, 47, 47, 49, 49, 49, 49,
    1, 39, 39, 39, 39, 41, 41, 41, 41, 43, 43, 43, 43, 45, 45, 45, 45, 47, 47, 47, 47, 49, 49, 49, 49
};

static const uint8_t    g_img2buf_bit[LED_CNT] =
{
    0x80, 0x80, 0x40, 0x20, 0x10, 0x80, 0x40, 0x20, 0x10, 0x80, 0x40, 0x20, 0x10, 0x80, 0x40, 0x20, 0x10, 0x80, 0x40, 0x20, 0x10, 0x80, 0x40, 0x20, 0x10,
    0x40, 0x08, 0x04, 0x02, 0x01, 0x08, 0x04, 0x02, 0x01, 0x08, 0x04, 0x02, 0x01, 0x08, 0x04, 0x02, 0x01, 0x08, 0x04, 0x02, 0x01, 0x08, 0x04, 0x02, 0x01,
    0x20, 0x80, 0x40, 0x20, 0x10, 0x80, 0x40, 0x20, 0x10, 0x80, 0x40, 0x20, 0x10, 0x80, 0x40, 0x20, 0x10, 0x80, 0x40, 0x20, 0x10, 0x80, 0x40, 0x20, 0x10,
    0x10, 0x08, 0x04, 0x02, 0x01, 0x08, 0x04, 0x02, 0x01, 0x08, 0x04, 0x02, 0x01, 0x08, 0x04, 0x02, 0x01, 0x08, 0x04, 0x02, 0x01, 0x08, 0x04, 0x02, 0x01,
    0x08, 0x80, 0x40, 0x20, 0x10, 0x80, 0x40, 0x20, 0x10, 0x80, 0x40, 0x20, 0x10, 0x80, 0x40, 0x20, 0x10, 0x80, 0x40, 0x20, 0x10, 0x80, 0x40, 0x20, 0x10,
    0x04, 0x08, 0x04, 0x02, 0x01, 0x08, 0x04, 0x02, 0x01, 0x08, 0x04, 0x02, 0x01, 0x08, 0x04, 0x02, 0x01, 0x08, 0x04, 0x02, 0x01, 0x08, 0x04, 0x02, 0x01,
    0x02, 0x80, 0x40, 0x20, 0x10, 0x80, 0x40, 0x20, 0x10, 0x80, 0x40, 0x20, 0x10, 0x80, 0x40, 0x20, 0x10, 0x80, 0x40, 0x20, 0x10, 0x80, 0x40, 0x20, 0x10,
    0x01, 0x08, 0x04, 0x02, 0x01, 0x08, 0x04, 0x02, 0x01, 0x08, 0x04, 0x02, 0x01, 0x08, 0x04, 0x02, 0x01, 0x08, 0x04, 0x02, 0x01, 0x08, 0x04, 0x02, 0x01,
    0x80, 0x80, 0x40, 0x20, 0x10, 0x80, 0x40, 0x20, 0x10, 0x80, 0x40, 0x20, 0x10, 0x80, 0x40, 0x20, 0x10, 0x80, 0x40, 0x20, 0x10, 0x80, 0x40, 0x20, 0x10,
    0x40, 0x08, 0x04, 0x02, 0x01, 0x08, 0x04, 0x02, 0x01, 0x08, 0x04, 0x02, 0x01, 0x08, 0x04, 0x02, 0x01, 0x08, 0x04, 0x02, 0x01, 0x08, 0x04, 0x02, 0x01,
    0x20, 0x80, 0x40, 0x20, 0x10, 0x80, 0x40, 0x20, 0x10, 0x80, 0x40, 0x20, 0x10, 0x80, 0x40, 0x20, 0x10, 0x80, 0x40, 0x20, 0x10, 0x80, 0x40, 0x20, 0x10,
    0x10, 0x08, 0x04, 0x02, 0x01, 0x08, 0x04, 0x02, 0x01, 0x08, 0x04, 0x02, 0x01, 0x08, 0x04, 0x02, 0x01, 0x08, 0x04, 0x02, 0x01, 0x08, 0x04, 0x02, 0x01,
    0x08, 0x80, 0x40, 0x20, 0x10, 0x80, 0x40, 0x20, 0x10, 0x80, 0x40, 0x20, 0x10, 0x80, 0x40, 0x20, 0x10, 0x80, 0x40, 0x20, 0x10, 0x80, 0x40, 0x20, 0x10,
    0x04, 0x08, 0x04, 0x02, 0x01, 0x08, 0x04, 0x02, 0x01, 0x08, 0x04, 0x02, 0x01, 0x08, 0x04, 0x02, 0x01, 0x08, 0x04, 0x02, 0x01, 0x08, 0x04, 0x02, 0x01,
    0x02, 0x80, 0x40, 0x20, 0x10, 0x80, 0x40, 0x20, 0x10, 0x80, 0x40, 0x20, 0x10, 0x80, 0x40, 0x20, 0x10, 0x80, 0x40, 0x20, 0x10, 0x80, 0x40, 0x20, 0x10,
    0x01, 0x08, 0x04, 0x02, 0x01, 0x08, 0x04, 0x02, 0x01, 0x08, 0x04, 0x02, 0x01, 0x08, 0x04, 0x02, 0x01, 0x08, 0x04, 0x02, 0x01, 0x08, 0x04, 0x02, 0x01
};

static void led_set_refresh_period(uint16_t period_us)
{
    LL_TIM_SetAutoReload(TIM3, period_us - 1U);
    LL_TIM_SetCounter(TIM3, 0U);
}

static void led_start_bitplane_dma(uint8_t bit)
{
    LL_SPI_DisableDMAReq_TX(SPI1);
    LL_DMA_DisableChannel(DMA1, LL_DMA_CHANNEL_1);
    LL_DMA_ClearFlag_GI1(DMA1);
    LL_DMA_ConfigAddresses(DMA1, LL_DMA_CHANNEL_1,
                           (uint32_t)g_led_breakdown.slice[bit].data,
                           (uint32_t)&SPI1->DR,
                           LL_DMA_DIRECTION_MEMORY_TO_PERIPH);
    LL_DMA_SetDataLength(DMA1, LL_DMA_CHANNEL_1, LED_BUFFER_SIZE);
    LL_DMA_EnableChannel(DMA1, LL_DMA_CHANNEL_1);
    LL_SPI_EnableDMAReq_TX(SPI1);
}

void led_init(void)
{
    memset(&g_led_breakdown, 0xFF, sizeof(g_led_breakdown));
    g_pending_bit = 0U;
    g_display_started = 0U;
    g_refresh_error_count = 0U;
}

void led_update_img(const uint8_t * pdata)
{
    uint8_t i, mask;
    uint16_t j;
    uint8_t * slice_ptr;
    const uint8_t * img_ptr;

    for (i = 0; i < LED_COLOR_DEPTH; ++i)
    {
        mask = 1 << (LED_COLOR_DEPTH - 1 -i);
        slice_ptr = g_led_breakdown.slice[i].data;
        img_ptr = pdata;

        ///< memset here will cause flicker
        // memset(slice_ptr, 0xFF, LED_BUFFER_SIZE);

        for (j = 0; j < LED_CNT; ++j, ++img_ptr)
        {
            if (*img_ptr & mask)
            {
                slice_ptr[g_img2buf_idx[j]] &= ~g_img2buf_bit[j];
            }
            else
            {
                slice_ptr[g_img2buf_idx[j]] |= g_img2buf_bit[j];
            }
        }
    }
}

void led_start_refresh(void)
{
    /* 首个位平面锁存之前保持输出关闭，避免上电时显示移位寄存器中的随机内容。 */
    OE_H;
    LAT_L;

    g_pending_bit = 0U;
    g_display_started = 0U;
    g_refresh_error_count = 0U;

    led_start_bitplane_dma(g_pending_bit);
    led_set_refresh_period(LED_DMA_RETRY_TIME_US);
    LL_TIM_ClearFlag_UPDATE(TIM3);
    LL_TIM_EnableCounter(TIM3);
}
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

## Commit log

2025-07-03 sync STM32G070 project
2025-07-07 finished LED driving
2025-07-08 Finished LED driver
2025-07-08 Remove redundant comments generated by STM32CubeMX
2025-07-30 on implementing CPP classes for animated gfx
    [front.SLDPRT, front.STL, front_nopiller.STL]
2025-10-18 on finishing fonts and testing animation task (still untested). next: implement timers and create 100Hz task scheduler.
2025-11-05 on implementing UART DMA communication
2025-12-08 [NEW] finished USART DMA TX and RX, with v1 packet handling.
2026-08-01 optimized SPI-DMA scheme

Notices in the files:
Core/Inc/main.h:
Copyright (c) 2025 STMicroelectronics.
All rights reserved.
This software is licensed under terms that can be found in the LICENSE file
